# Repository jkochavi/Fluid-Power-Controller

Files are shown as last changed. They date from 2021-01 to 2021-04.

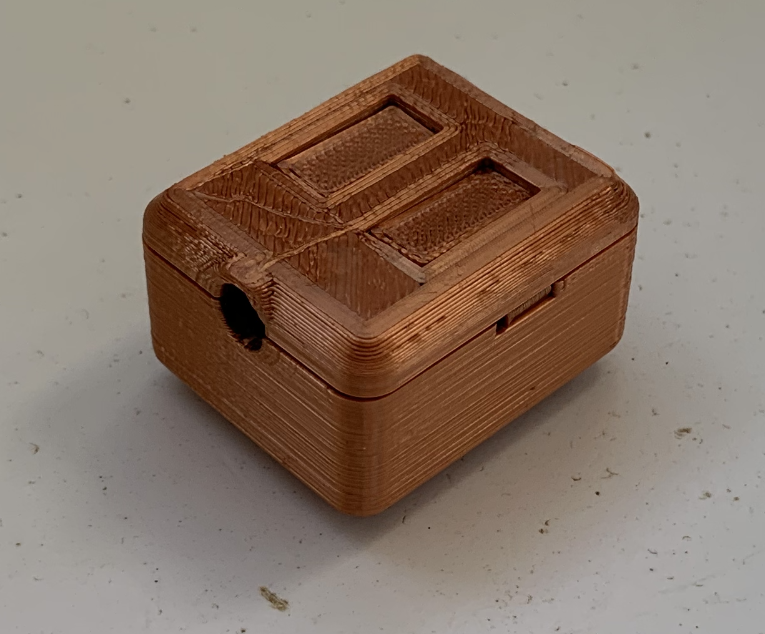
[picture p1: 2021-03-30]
wiki_Support_Files/Design Verification/Setup.png

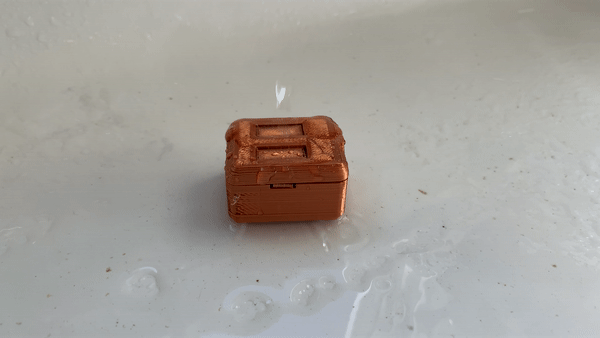
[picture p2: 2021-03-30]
wiki_Support_Files/Design Verification/FullOn.gif

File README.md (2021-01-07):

# Fluid-Power-Controller
This software requires the use of STM32FreeRTOS.

The following files and libraries were created by other groups. 

Please download the following libraries/source files into the source code for this project:
- PrintStream.h
- STM32FreeRTOS.h
- "Easy Nextion Library" by Seithan
    - https://github.com/Seithan/EasyNextionLibrary.git
- "arduino-mcp2515" library by autowp
    - https://github.com/autowp/arduino-mcp2515.git
- ME 507 support files by spluttflob
    - All files necessary for inter-task variable sharing in FreeRTOS

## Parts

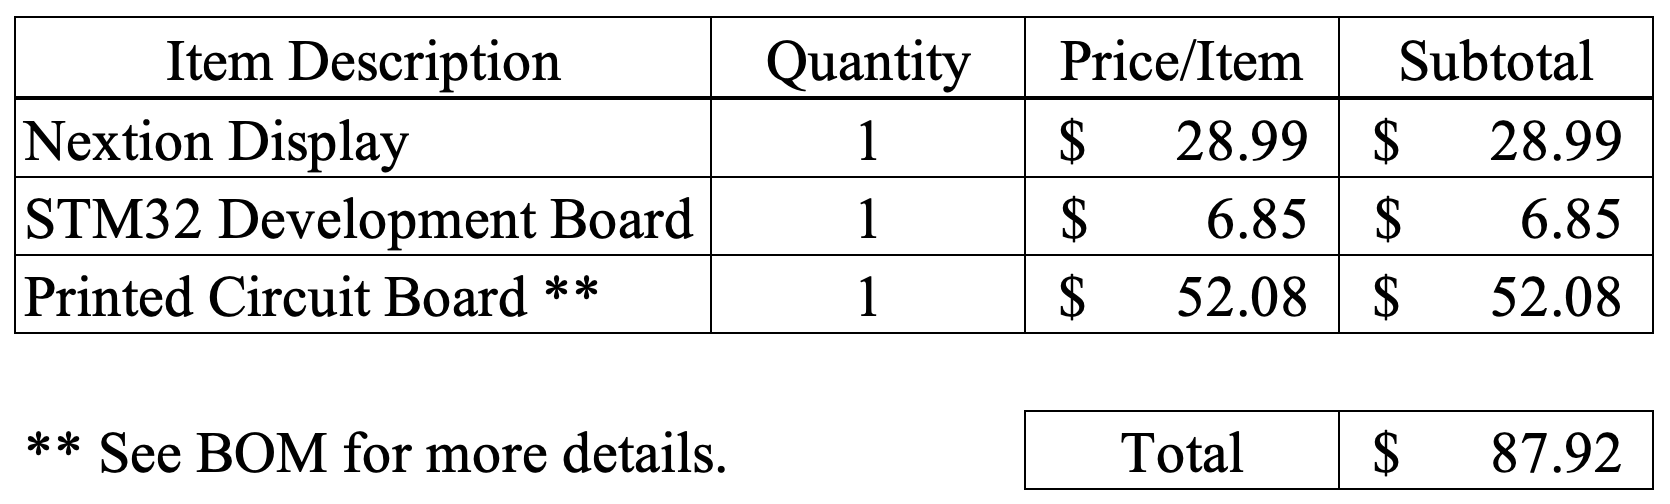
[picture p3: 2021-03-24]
wiki_Support_Files/totalCosts.png

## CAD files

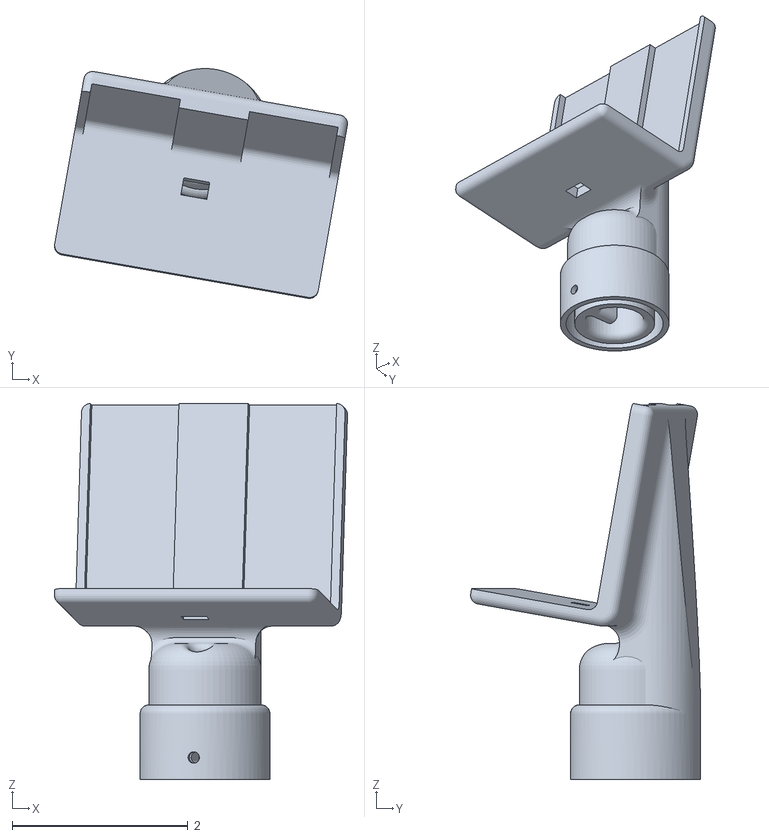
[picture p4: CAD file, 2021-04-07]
STL Files/Screen Stand.stl
3.34 x 2.62 x 4.28

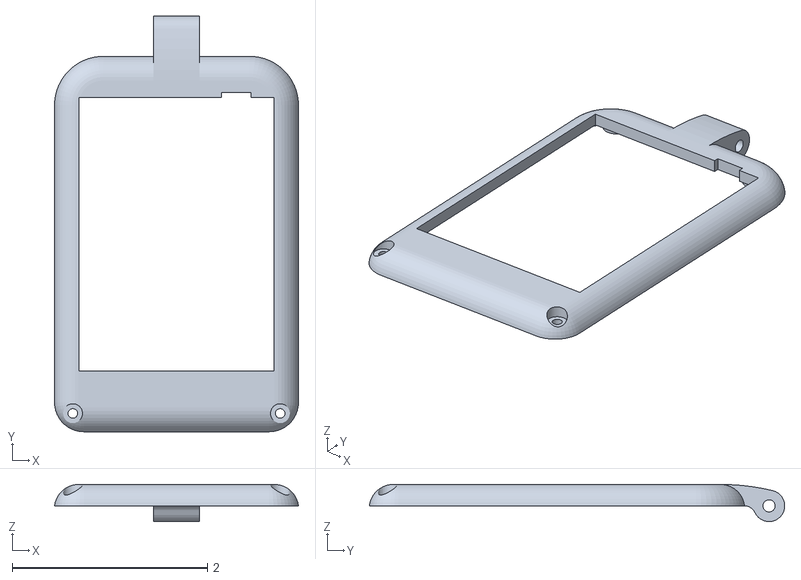
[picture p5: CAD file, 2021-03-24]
STL Files/Screen Case Top.stl
2.50 x 4.26 x 0.381

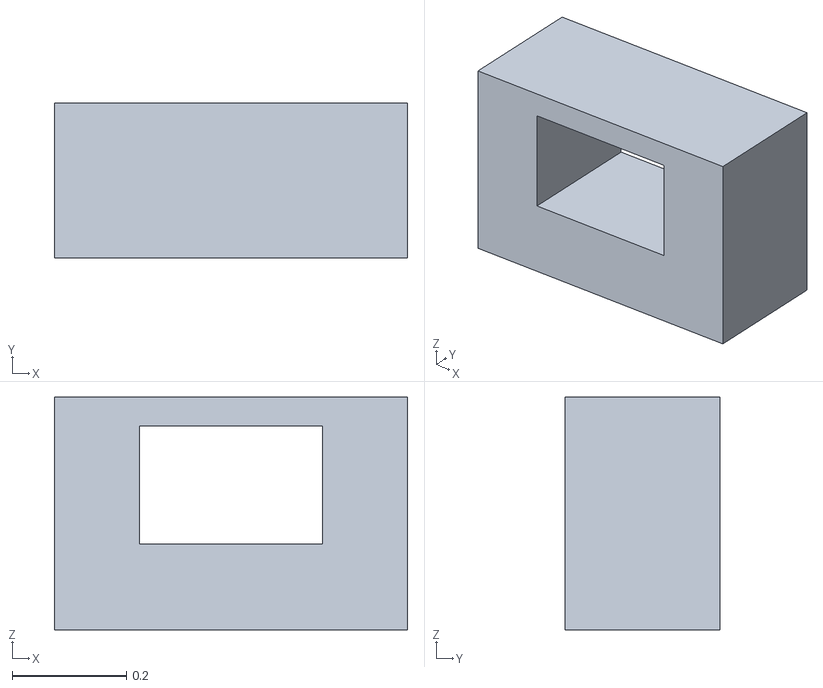
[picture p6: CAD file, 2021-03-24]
STL Files/Button Case Presser.stl
0.618 x 0.272 x 0.407

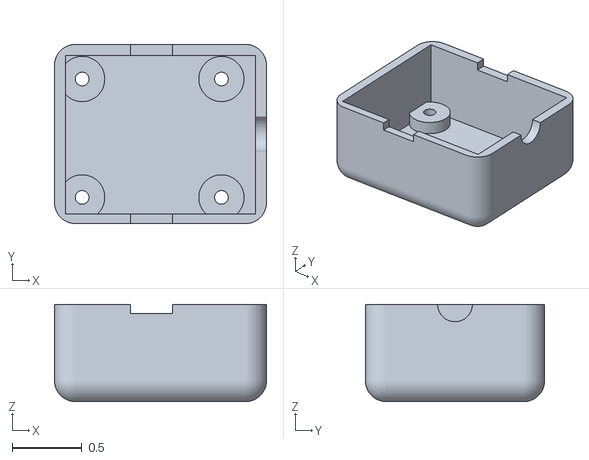
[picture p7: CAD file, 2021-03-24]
STL Files/Button Case Bottom.stl
1.52 x 1.29 x 0.698

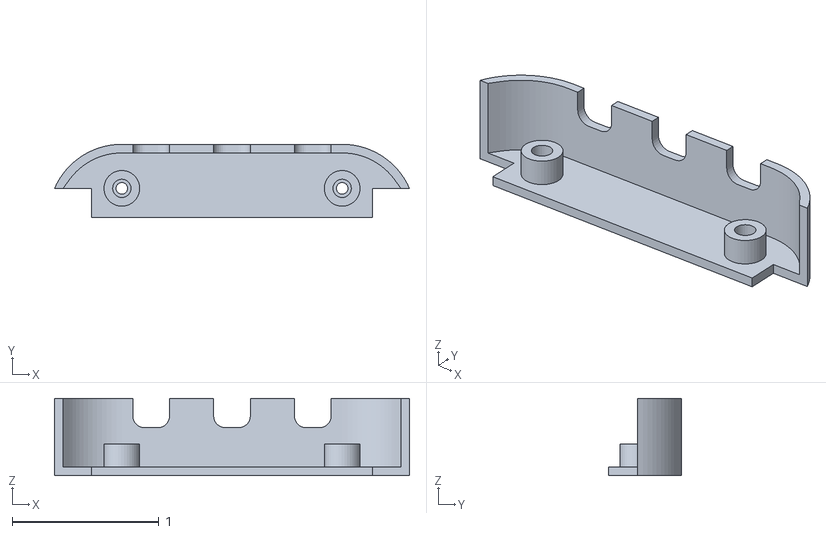
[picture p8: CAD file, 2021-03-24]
STL Files/Screen Case Port Cap.stl
2.42 x 0.5 x 0.526

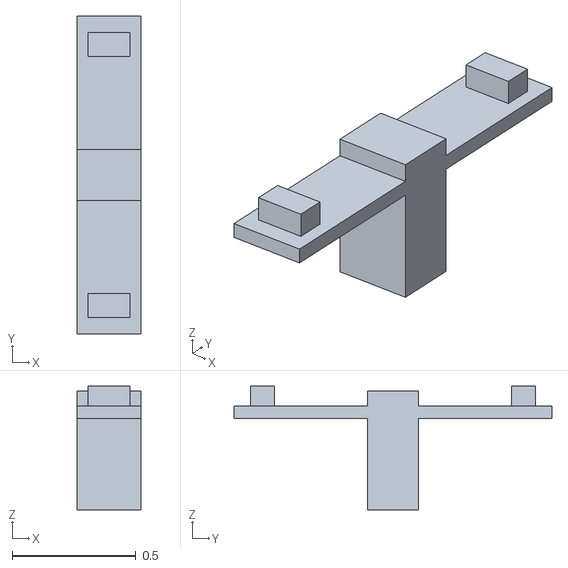
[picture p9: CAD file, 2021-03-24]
STL Files/Button Case Captive Crossbar.stl
0.261 x 1.29 x 0.5

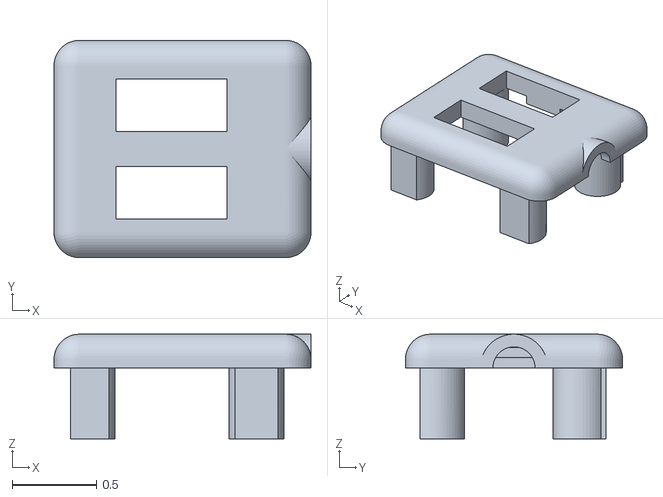
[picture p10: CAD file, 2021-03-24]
STL Files/Button Case Top.stl
1.52 x 1.29 x 0.62

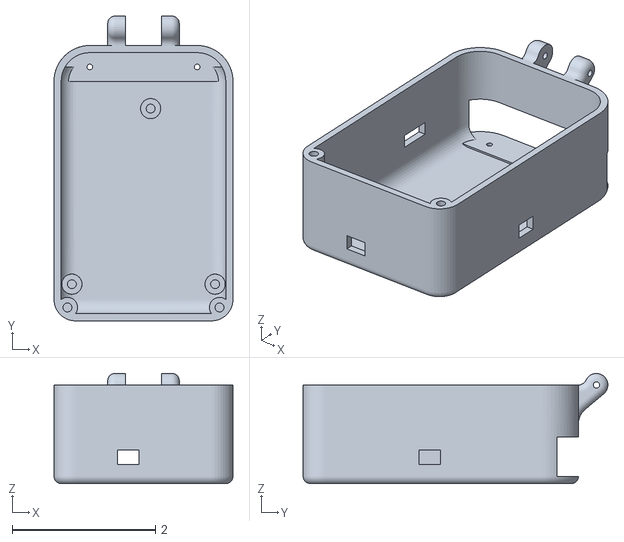
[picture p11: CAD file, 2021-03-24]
STL Files/Screen Case Bottom.stl
2.50 x 4.26 x 1.54

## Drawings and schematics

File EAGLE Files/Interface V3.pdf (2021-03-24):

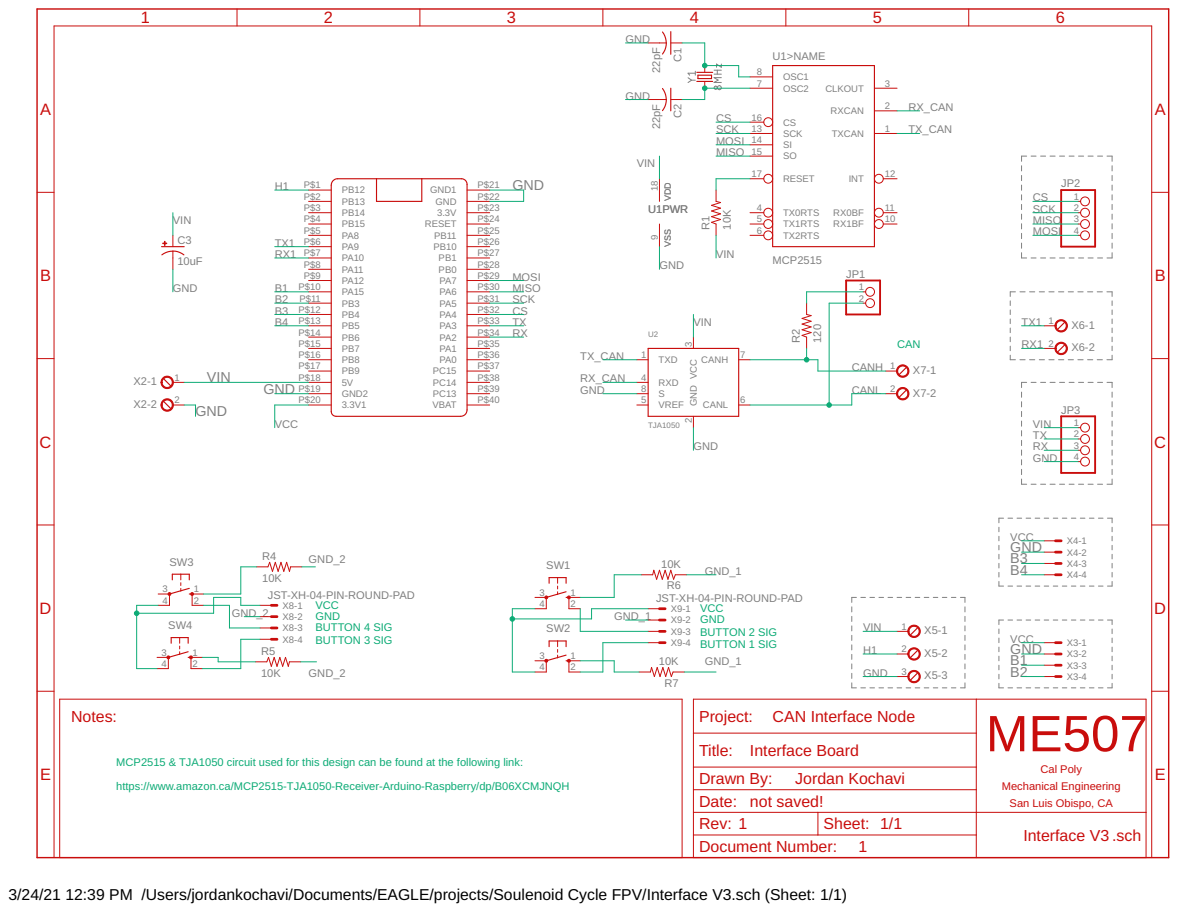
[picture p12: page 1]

18 9 VSS VDD VSS VDD U1PWR

MCP2515 & TJA1050 circuit used for this design can be found at the following link: https://www.amazon.ca/MCP2515-TJA1050-Receiver-Arduino-Raspberry/dp/B06XCMJNQH

Mechanical Engineering
San Luis Obispo, CA
Interface V3

3/24/21 12:39 PM /Users/jordankochavi/Documents/EAGLE/projects/Soulenoid Cycle FPV/Interface V3.sch (Sheet: 1/1)

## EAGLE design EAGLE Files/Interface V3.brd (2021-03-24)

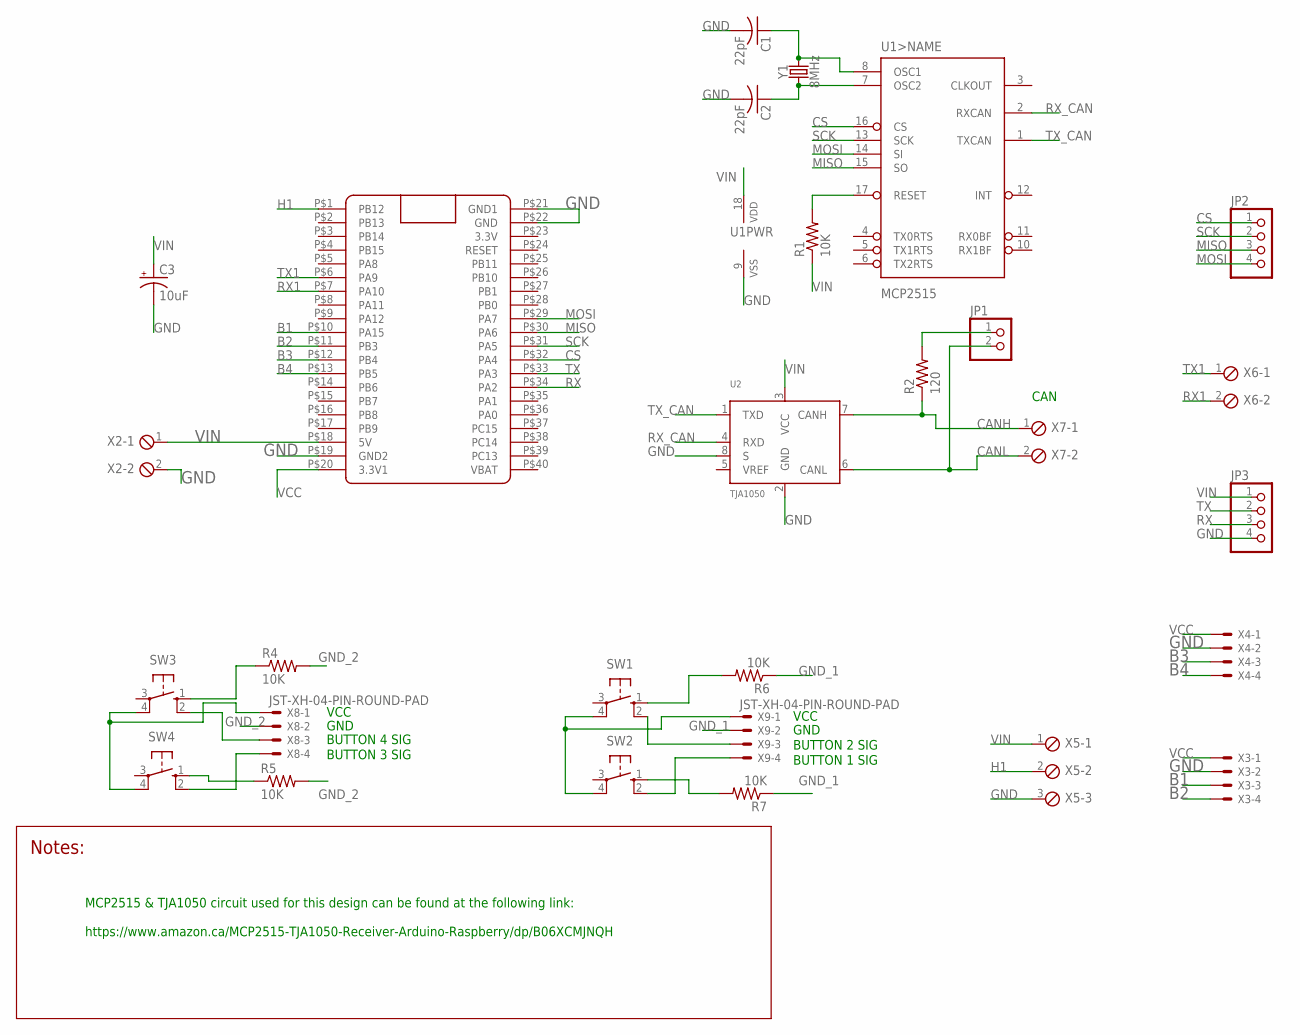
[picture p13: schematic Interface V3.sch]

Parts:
C1, C2: 22pF; C0805
C3: 10uF; CT3216
JP1: PINHD-1X2; 1X02
JP2, JP3: PINHD-1X4; 1X04
R1, R4, R5, R6, R7: 10K; R0805
R2: 120; R0805
SW1, SW2, SW3, SW4: PUSHBUTTON; B3F-10XX
U1: MCP2515; SO18W
U2: TJA1050; SOT96-1
U$1: BLUE_PILL
X2, X6, X7: SCREWTERM_2P_381; 2POL381
X3, X4: JST-XH-04-PIN-LONG-PAD; JST-XH-04-PACKAGE-LONG-PAD
X5: SCREWTERM_3P_381; 3POL381
X8, X9: JST-XH-04-PIN-ROUND-PAD; JST-XH-04-PACKAGE-ROUND-PAD
Y1: 8MHz; HC49US

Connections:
B1: U$1.P$10 (PA15), X3.3
B2: U$1.P$11 (PB3), X3.4
B3: U$1.P$12 (PB4), X4.3
B4: U$1.P$13 (PB5), X4.4
CANH: R2.1, U2.7 (CANH), X7.1
CANL: JP1.2, U2.6 (CANL), X7.2
CS: JP2.1, U1.16 (CS), U$1.P$32 (PA4)
GND: C1.2, C2.2, C3.-, JP3.4, U1.9 (VSS), U2.2 (GND), U2.8 (S), U$1.P$19 (GND2), U$1.P$21 (GND1), U$1.P$22 (GND), X2.2, X3.2, X4.2, X5.3
GND_1: R6.1, R7.1, X9.2
GND_2: R4.2, R5.2, X8.2
H1: U$1.P$1 (PB12), X5.2
MISO: JP2.3, U1.15 (SO), U$1.P$30 (PA6)
MOSI: JP2.4, U1.14 (SI), U$1.P$29 (PA7)
unnamed: C2.1, U1.7 (OSC2), Y1.1
unnamed: C1.1, U1.8 (OSC1), Y1.2
unnamed: R1.2, U1.17 (RESET)
unnamed: SW3.2 (S1), X8.3
unnamed: JP1.1, R2.2
unnamed: SW4.2 (S1), X8.4
unnamed: R4.1, SW3.1 (S)
unnamed: R5.1, SW4.1 (S)
unnamed: SW3.4 (P1), SW4.4 (P1), X8.1
unnamed: R6.2, SW1.1 (S)
unnamed: R7.2, SW2.1 (S)
unnamed: SW1.2 (S1), X9.3
unnamed: SW2.2 (S1), X9.4
unnamed: SW1.4 (P1), SW2.4 (P1), X9.1
RX: JP3.3, U$1.P$34 (PA2)
RX1: U$1.P$7 (PA10), X6.2
RX_CAN: U1.2 (RXCAN), U2.4 (RXD)
SCK: JP2.2, U1.13 (SCK), U$1.P$31 (PA5)
TX: JP3.2, U$1.P$33 (PA3)
TX1: U$1.P$6 (PA9), X6.1
TX_CAN: U1.1 (TXCAN), U2.1 (TXD)
VCC: U$1.P$20 (3.3V1), X3.1, X4.1
VIN: C3.+, JP3.1, R1.1, U1.18 (VDD), U2.3 (VCC), U$1.P$18 (5V), X2.1, X5.1

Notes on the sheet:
VCC
GND
BUTTON 4 SIG
BUTTON 3 SIG
BUTTON 2 SIG
BUTTON 1 SIG
CAN
MCP2515 & TJA1050 circuit used for this design can be found at the following link: https://www.amazon.ca/MCP2515-TJA1050-Receiver-Arduino-Raspberry/dp/B06XCMJNQH

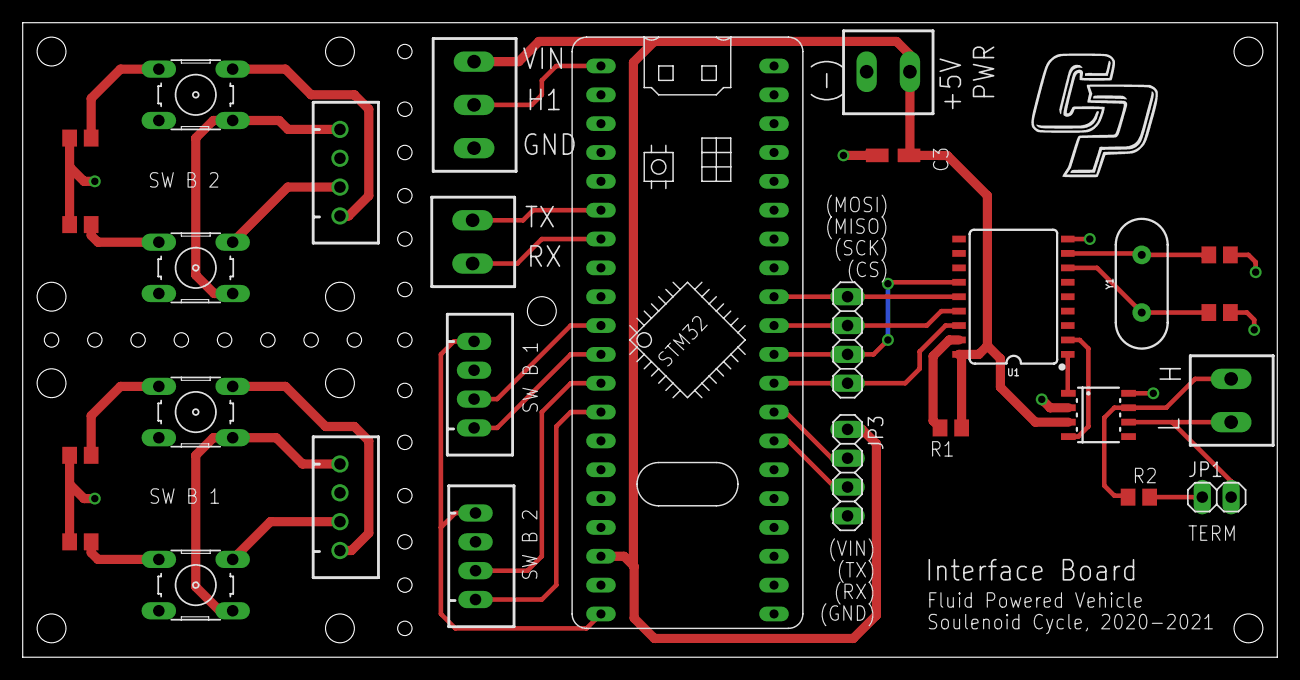
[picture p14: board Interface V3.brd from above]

Board: 2 copper layers, 110.5 x 55.9 mm, 28 parts (0 on the bottom side), 36 nets.

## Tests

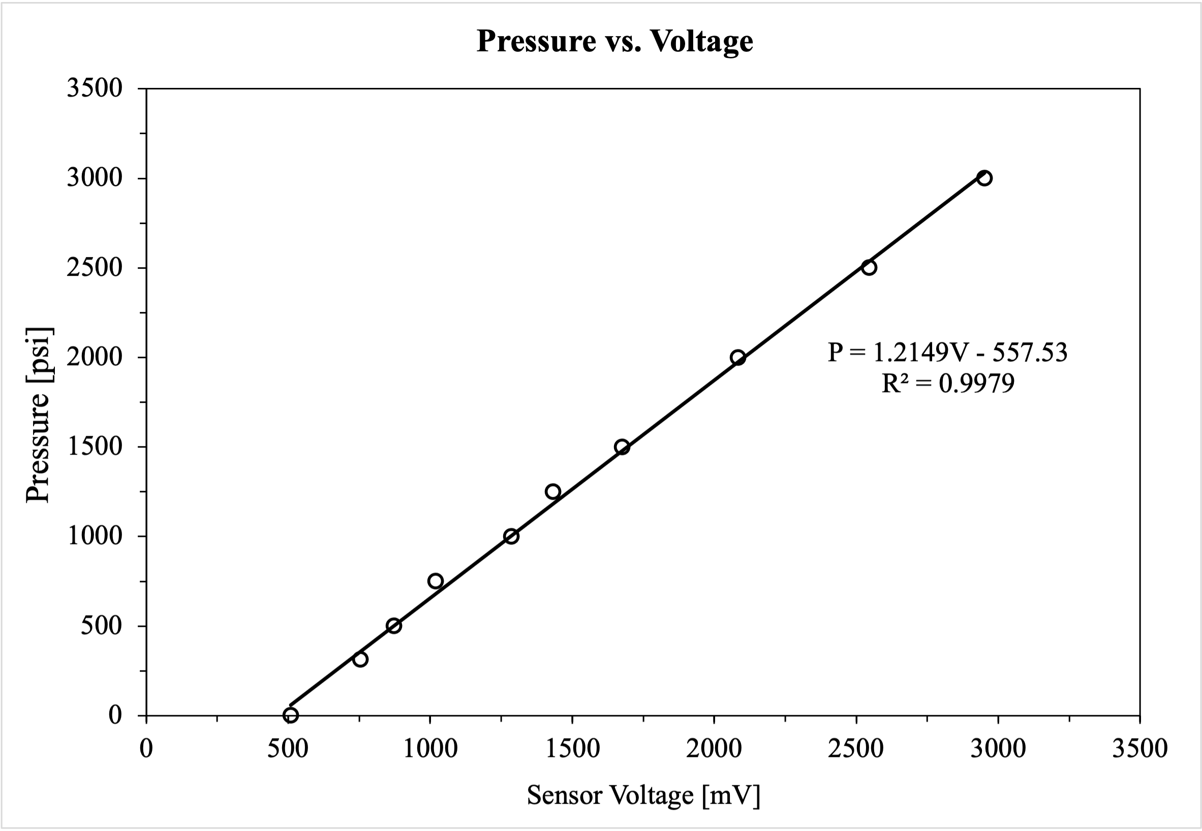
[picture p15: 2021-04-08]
wiki_Support_Files/experimental.png

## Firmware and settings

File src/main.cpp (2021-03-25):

/** @file main.cpp
 *    This file contains the main program structure for the vehicle's 
 *    interface controller. It creates three RTOS tasks and begins the 
 *    task scheduler. The three tasks are used with the custom Interface
 *    header file.
 *
 *  @author  Jordan Kochavi
 *  @date    8 Dec 2020 Original file
 */

#include "Arduino.h"                              // Include Arduino library
#include "PrintStream.h"                          // Include PrintStream library
#include "STM32FreeRTOS.h"                        // Include FreeRTOS library
#include "Interface.h"                            // Include custom interface library

/** @brief   Arduino setup function which runs once at program startup.
 *  @details This function sets up a serial port for communication and creates
 *           the tasks which will be run.
 */
void setup()                                      
{
    Serial.begin(115200);                         // Begin Serial @ 115200 baud
    delay(500);                                   // Pause 0.5 seconds
    Serial.println("Starting program...");        // Print for debugging
    xTaskCreate (task_HALL1,                      // Create task for user interface
                 "Bike Speed",                    // Name for printouts
                 512,                             // Stack size
                 NULL,                            // Parameters for task fn.
                 1,                               // Priority
                 NULL);                           // Task handle
    xTaskCreate (task_CAN,                        // Create task for user interface
                 "CAN communication",             // Name for printouts
                 1024,                            // Stack size
                 NULL,                            // Parameters for task fn.
                 2,                               // Priority
                 NULL);                           // Task handle
    xTaskCreate (task_display,                    // Create task for user interface
                 "Nextion communication",         // Name for printouts
                 1024,                             // Stack size
                 NULL,                            // Parameters for task fn.
                 3,                               // Priority
                 NULL);                           // Task handle
    vTaskStartScheduler ();                       // Begin task scheduler
}

/** @brief   Arduino's low-priority loop function, which we don't use.
 *  @details A non-RTOS Arduino program runs all of its continuously running
 *           code in this function after @c setup() has finished. When using
 *           FreeRTOS, @c loop() implements a low priority task on most
 *           microcontrollers, and crashes on some others, so we'll not use it.
 */
void loop()
{

}

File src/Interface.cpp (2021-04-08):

/** @file Interface.cpp
 * This file contains the function files for the RTOS
 * tasks used with the interface controller. It manages
 * three tasks: display, CAN, and hall effect. In the 
 * display task, the controller interfaces with a 
 * Nextion display using the EasyNextionLibrary header
 * file. The controller communicates with the Nextion
 * using UART. In the CAN task, the controller interfaces
 * with an MCP2515 CAN controller using SPI, which outputs
 * a CAN signal to the CAN bus. In the hall effect task,
 * the controller reads a GPIO pin using a polling method.
 * 
 * As discussed in the section, \ref s_software, the task
 * with the highest priority is task_HALL1(), which must
 * quickly poll the hall effect sensor to measure the 
 * speed of the vehicle. A high-level task diagram is
 * shown in Figure 1.
 * 
 * <img src="https://raw.githubusercontent.com/jkochavi/Fluid-Power-Controller/master/wiki_Support_Files/fig19.png" style="width:400px;">
 * <br /><b>Figure 1.</b> Inter-controller system boundary diagram.
 *
 * The sensor task, task_HALL1() operates in a simple 
 * Finite State Machine (FSM) that switches states
 * based on the high/low status of the hall effect signal. An
 * FSM diagram is shown in the figure below.
 * 
 * <img src="https://raw.githubusercontent.com/jkochavi/Fluid-Power-Controller/master/wiki_Support_Files/fsm.png" style="width:400px;">
 * <br /><b>Figure 2.</b> FSM diagram for task_HALL1().
 * 
 * In State 1, the task continuously waits for a hall effect trigger. Since
 * the sensor is active-low, the task uses the function debounce() to identify
 * when the signal transitions from high to low. When this change is identified,
 * the task calculates the speed of the vehicle and stores it in two inter-task
 * variables: bikeSpeed and floatSpeed. See variable descriptions for more 
 * information. After the speed is calculated, the task transitions to State 2
 * to wait until the signal transitions back to high. When the signal returns
 * from low to high, the task transitions back to State 1 to wait for the next
 * pulse.
 * 
 *  @author  Jordan Kochavi
 *  @date    8 Dec 2020 Original file
 */

#include "Interface.h"           // Include custom interface library
#include "taskshare.h"           // Include libary for inter-task variables
#include "taskqueue.h"           // Include library for inter-task buffers
#include "EasyNextionLibrary.h"  // Include Nextion library
#include "STM32FreeRTOS.h"       // Include FreeRTOS library
#include "SPI.h"                 // Include SPI library
#include "mcp2515.h"             // Include MCP2515 library
/// @brief Macro definition for GPIO pin attached to coast button.
#define coastButton  PA15        // GPIO pin for coast mode button
/// @brief Macro definition for GPIO pin attached to direct drive button.
#define directButton PB3         // GPIO pin for direct drive button
/// @brief Macro definition for GPIO pin attached to boost mode button
#define boostButton  PB4         // GPIO pin for boost mode button
/// @brief Macro definition for GPIO pin attached to regenerative braking button.
#define regenButton  PB5         // GPIO pin for regen mode button
/// @brief Macro definition for GPIO pin attached to hall effect sensor
#define HALL1        PB12        // GPIO pin for hall effect sensor
/// @brief Macro definition for GPIO pin atached to the MCP2515 chip select
#define CS           PA4         // Chip select pin for MCP2515

/** @brief This variable keeps track of which drive mode the vehicle is in. 
 *         This value is when a button is pressed. 
 */
uint8_t buttonState = 1;                                    // 1->Direct 2->Coast 3->Regen 4->Boost 5->Pedal
/** @brief This variable is changed by the display task, and keeps
 *         track of when the drive mode text on the Nextion display 
 *         needs to be updated.
 */
uint8_t previousButtonState_DSP = 255;                      // Init to force display update
/** @brief This variable is changed by the CAN task, and keeps
 *  track of when the controller needs to push an update
 * to the PLC.
 */
uint8_t previousButtonState_CAN = 255;                      // Init to force CAN transmission
/** @brief   Inter-task variable for storing accumulator pressure values. 
 *  @details Storing these values in a Share makes up for any mismatch
 *           in transmission frequencies between the PLC and this
 *           controller. 
 */
Share <int32_t> accumulatorPressure;
/** @brief   Inter-task variable for storing bike speed values. 
 *  @details Storing these values in a Share makes up for any 
 *           mismatch in transmission frequencies between the 
 *           display and hall effect tasks.
 */
Share <int32_t> bikeSpeed;
/** @brief   Inter-task variable for storing "float" speed values.
 *  @details The Nextion display is incapable of working with 
 *           floating-point numbers. Instead, Nextion Editor has
 *           a way of "faking" floating point numbers by splicing
 *           an integer with an artifical decimal point, and then
 *           shifting it around to simulate a decimal number. 
 *           Therefore, to display a the vehicle speed in the 
 *           format, XX.X, we can multiply the calculated speed
 *           by 10, and then the Nextion will shift the decimal 
 *           place left by 1. For example, if task_HALL1() 
 *           were to calculate a speed of 10.52 mph, the task
 *           will first multiply by 10 and then round to the 
 *           nearest integer, which will equal 105. Then, 
 *           task_display() will send the number 105 to the Nextion.
 *           The Nextion's software will store the number 105 in 
 *           its simulated floating point number variable, with 
 *           a decimal point inserted 1 digit to the left. Thus,
 *           the screen will display: 10.5. 
 */
Share <int32_t> floatSpeed;
/** @brief   Share that stores status of CAN connection.
 *  @details A value of TRUE means that a CAN connection is established,
 *           and a value of FALSE means that an error has occured.
 */
Share <bool> CANconnected;
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

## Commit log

2021-03-08 Modified button assignments.
2021-03-24 Added EAGLE files.
    [Interface V3.brd, Interface V3.sch]
2021-03-24 Added new pages for EAGLE files.
    [Button Case Bottom.stl, Button Case Captive Crossbar.stl, Button Case Presser.stl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]
2021-03-24 Added links to STL files.
2021-03-25 Implemented FSM for hall effect sensor. Fixed calculations.
    [Interface.cpp, main.cpp]
2021-03-25 Updated documentation for hall effect task.
2021-03-30 Added pictures from button module water testing.
2021-04-01 Added function to convert raw sensor reading into psi.
2021-04-03 Fixed bug that prevented drive mode reception from Nextion.
    [Interface.cpp]
2021-04-03 Fixed pressure transducer calibration.
    [Interface.cpp]
2021-04-04 Fixed pressure calculation.
2021-04-04 Added pressure transducer calibration curve.
2021-04-05 Got rid of pressure calculation offset.
2021-04-07 Added STL file for screen stand.
    [Screen Stand.stl]
2021-04-08 Fixed pressure calculation to calibrated curve fit.
    [Interface.cpp]
2021-04-08 Added calibration plot.
2021-04-12 Switching out for better quality picture.
2021-04-12 Switching to add logo to picture.

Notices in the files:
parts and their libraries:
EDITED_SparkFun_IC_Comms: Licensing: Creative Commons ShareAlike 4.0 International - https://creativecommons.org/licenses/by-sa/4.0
